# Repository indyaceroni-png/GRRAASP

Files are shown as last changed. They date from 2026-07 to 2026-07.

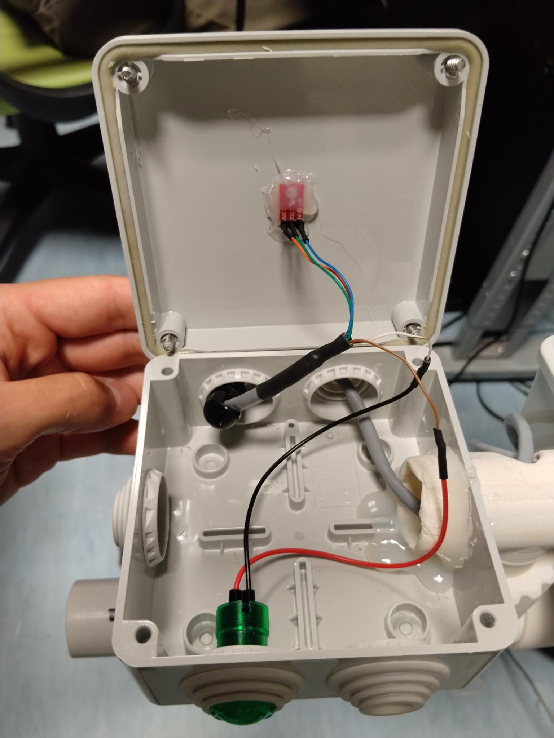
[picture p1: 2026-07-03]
Supplemental Files/Supplemental Files 3/FigureS3.jpeg

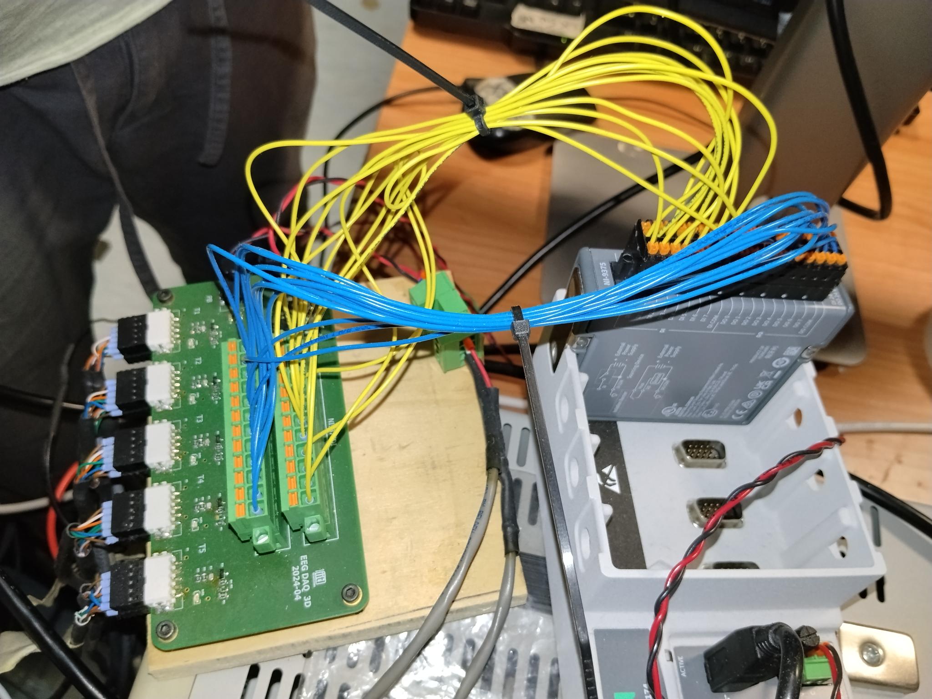
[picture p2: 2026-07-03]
Supplemental Files/Supplemental Files 3/FigureS5.jpeg

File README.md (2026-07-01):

# GRRAASP
This repository contains the LabVIEW software and documentation required to operate the Guided Reaching and Repositioning Adjustable Assessment Platform (GRRAASP), a modular and sensorized setup designed for the standardized neural, muscular, biomechanical, and behavioral assessment of reach-grasp-transport tasks

Folder GRRAASP_LabView contains:
- GRRAASP_main.vi contains the main file controlling the platform.
- Check File Path.vi is needed to set the file path to save logs of the platform.

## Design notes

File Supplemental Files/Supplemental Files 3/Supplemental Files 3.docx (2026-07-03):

Figure S1. Schematic of GRAASP device. Red numbers: (0) 0_baseBracket.stl, (1) 1_middleBracket.stl, (2) 2_topBracket.stl, (3) 3_armLockingSocket.stl, (4) 4_platformLockingSocket.stl, (5) 5_platformTMount.stl, (6) 6_platformSwivelJoint.stl, (7) 7_armTMount.stl, (8) 8_cableClip.stl, (9) 9_lockingRing.stl. Blue numbers: (1)200cm PVC pipes, (2) 55cm PVC pipes, (3) junction box, (4) infrared sensor hole, (5) LED light. Yellow numbers: (1) cylindrical grasp object, (2) spherical grasp object. Black numbers: (1) mobile base, (2) pushbutton

Figure S2. (Left) Detailed view of the installation procedure, showing the insertion of the three 200cm PVC pipes into the 0_baseBracket.stl (Bottom Bracket) and the 1_middleBracket.stl (Middle Alignment Bracket), and the subsequent securing of the entire structure to the central shaft to the mobile base with m4 screws. (Right) Detailed view of the 9_cableClip holding ethernet cables.

Figure S3. Detailed view of the junction box (interaction platform), illustrating the internal wiring and component placement. The electrical connections are mapped as follows: brown wire to LED Positive (Anode), white wire to LED Negative (Cathode), orange wire to Infrared Sensor Positive (VCC), blue wire to Infrared Sensor Ground (GND), and green wire to Infrared Sensor Signal/Data (OUT). To provide strain relief and mechanical stability, the Ethernet cable is looped inside the enclosure. It then exits laterally, passing through the 6_platformSwivelJoint.stl component, which is fitted into a custom-drilled hole on the side of the junction box and permanently secured with glue for added structural integrity.

Figure S4. Detailed view of the custom PCB illustrating the wire placement. The five crimped wires from each cable are inserted into their designated connectors on the board. The connectors are organized into two rows: the top row corresponds to platform indexes 1 through 5 (arranged from left to right), and the bottom row corresponds to platform indexes 6 through 10 (arranged from left to right)

Figure S5. Detailed view of the custom PCB and DAQ module integration. The setup features two pluggable terminal blocks (FKCN 2,5/12-ST-5,08, catalog number 1754665 in Materials.xlsx): one dedicated to the infrared sensors (yellow wires) and another for the LEDs (blue wires). Each pin from these terminal blocks is individually wired to its corresponding input/output pin on the NI-9375 module. The fully wired NI-9375 module is housed within the NI cDAQ-9174 chassis.

Figure S6. Close-up view of the custom PCB, detailing the specific terminal connections: (a) the power supply terminal connector, and (b) the push-button terminal connector.

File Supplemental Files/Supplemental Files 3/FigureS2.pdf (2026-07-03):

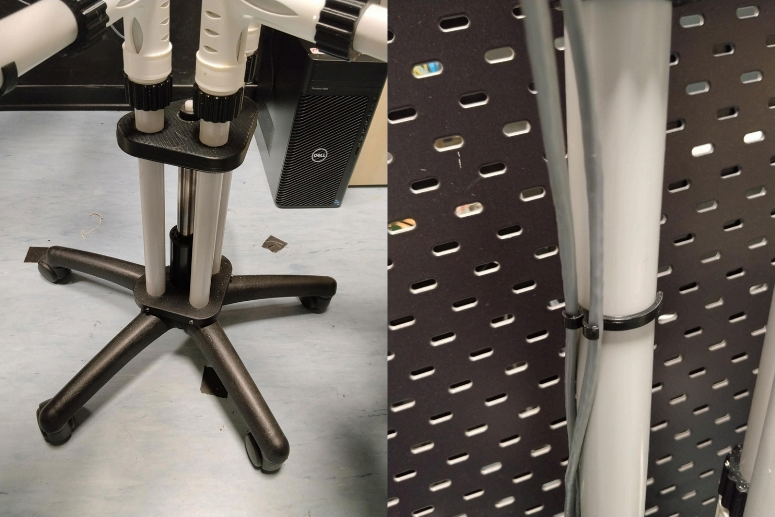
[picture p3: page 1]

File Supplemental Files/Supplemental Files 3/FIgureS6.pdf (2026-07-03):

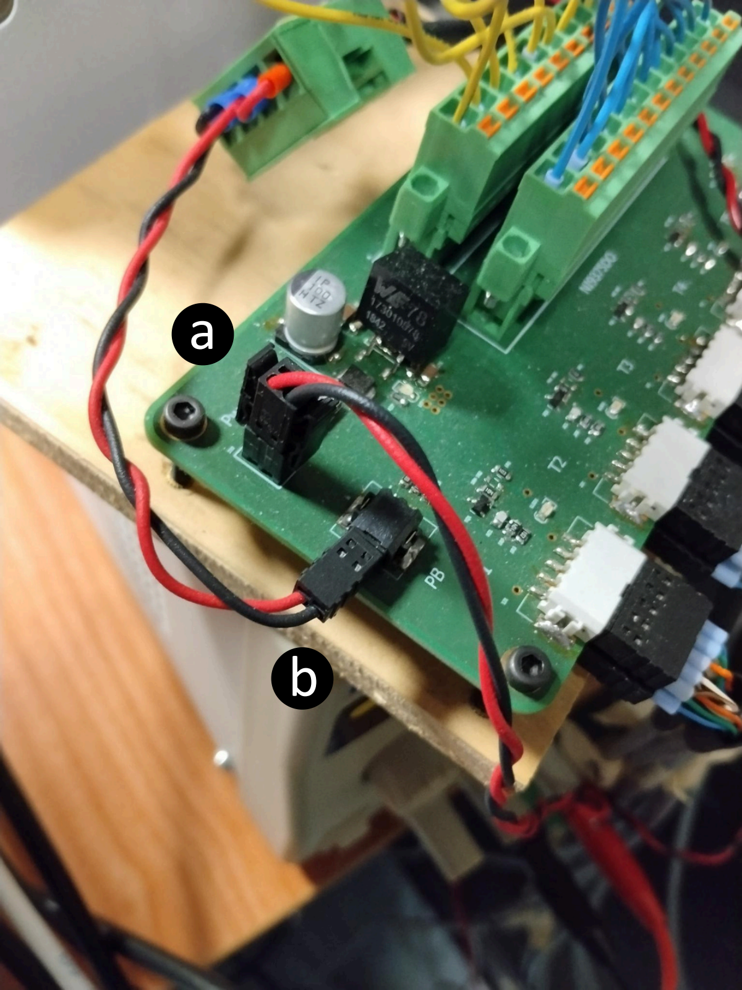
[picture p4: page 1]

a

b

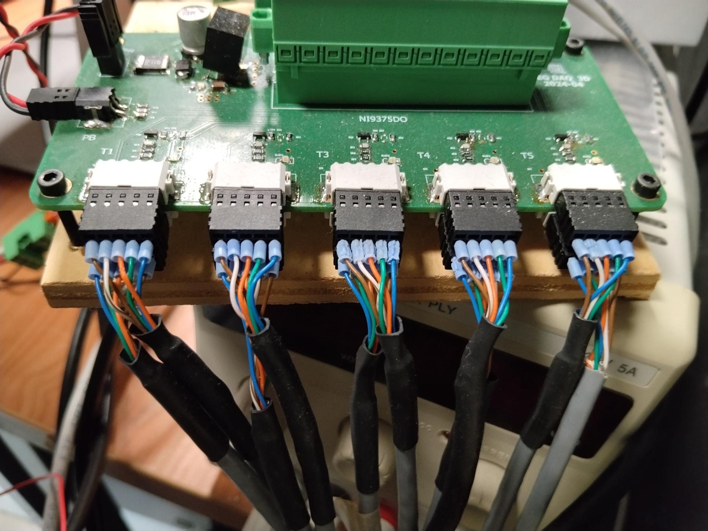
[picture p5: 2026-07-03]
Supplemental Files/Supplemental Files 3/FigureS4.jpeg

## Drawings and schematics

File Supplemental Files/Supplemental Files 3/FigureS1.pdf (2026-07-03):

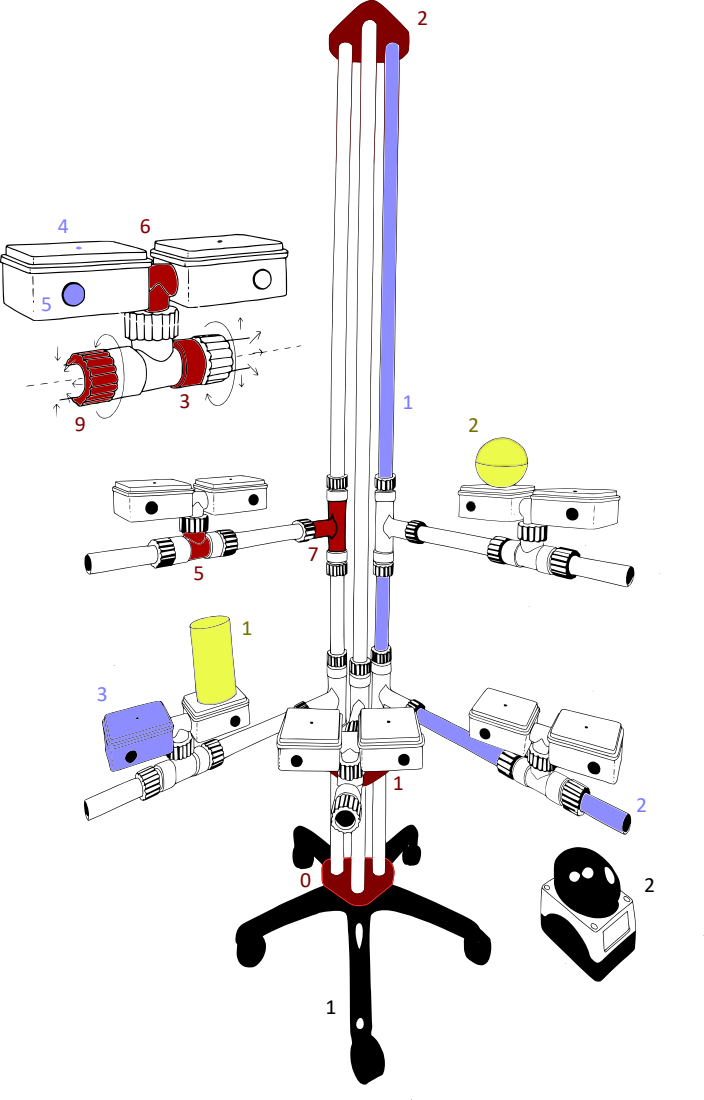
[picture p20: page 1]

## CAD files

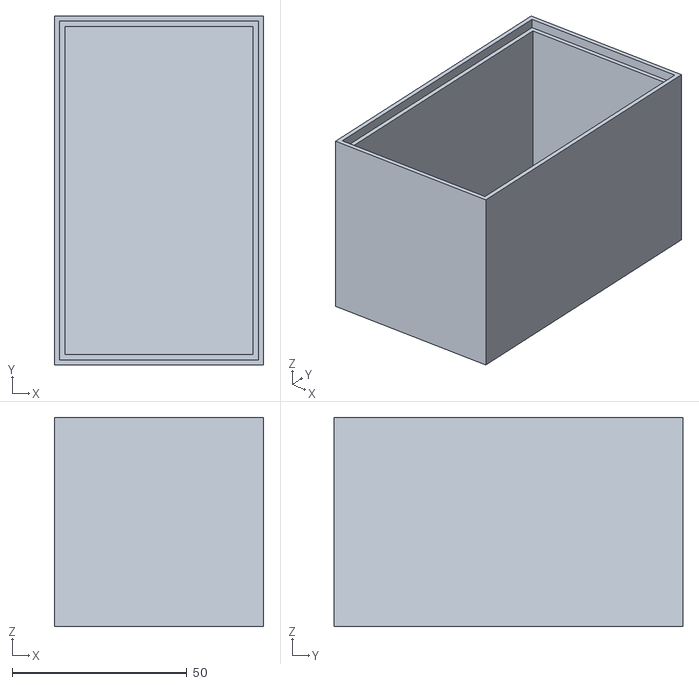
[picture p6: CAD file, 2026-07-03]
Supplemental Files/Supplemental FIles 1/keygrip_0.stl
60.0 x 100.0 x 60.0

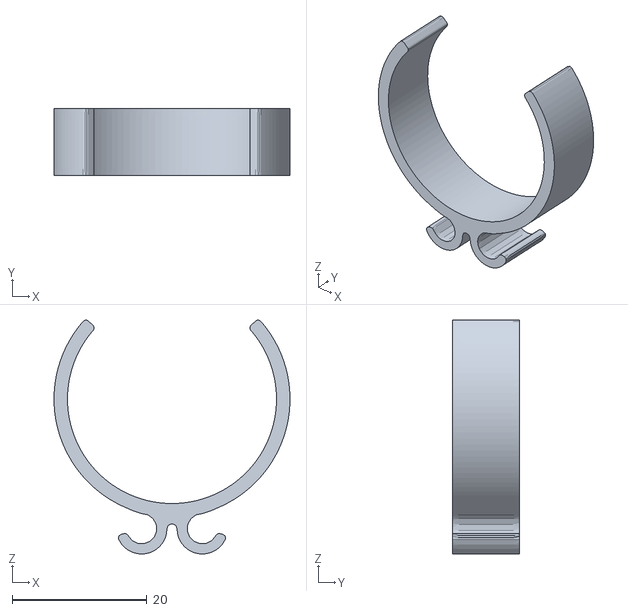
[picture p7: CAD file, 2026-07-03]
Supplemental Files/Supplemental FIles 2/8_cableClip.stl
35.0 x 10.0 x 34.7

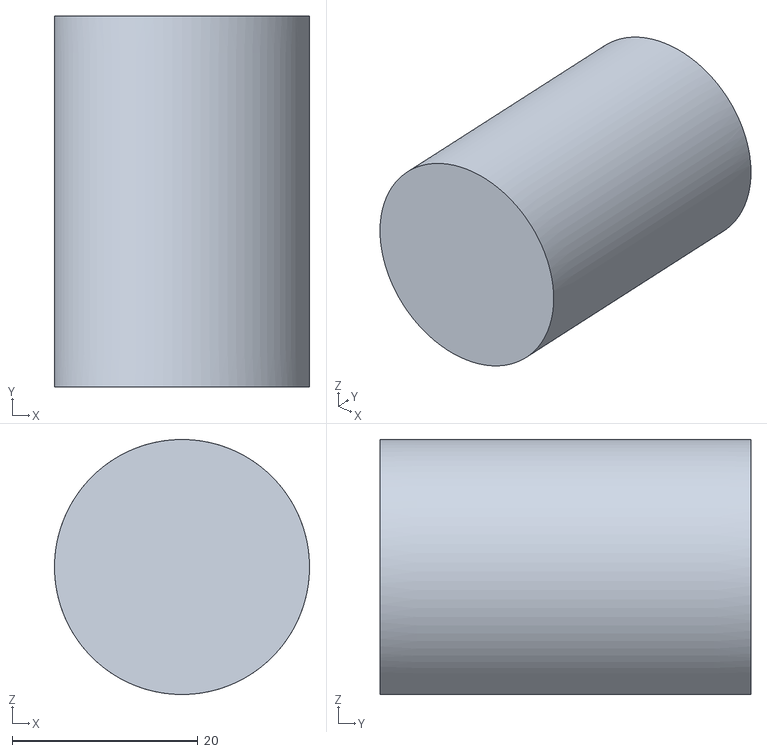
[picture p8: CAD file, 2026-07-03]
Supplemental Files/Supplemental FIles 1/weightSupport.stl
27.5 x 40.0 x 27.5

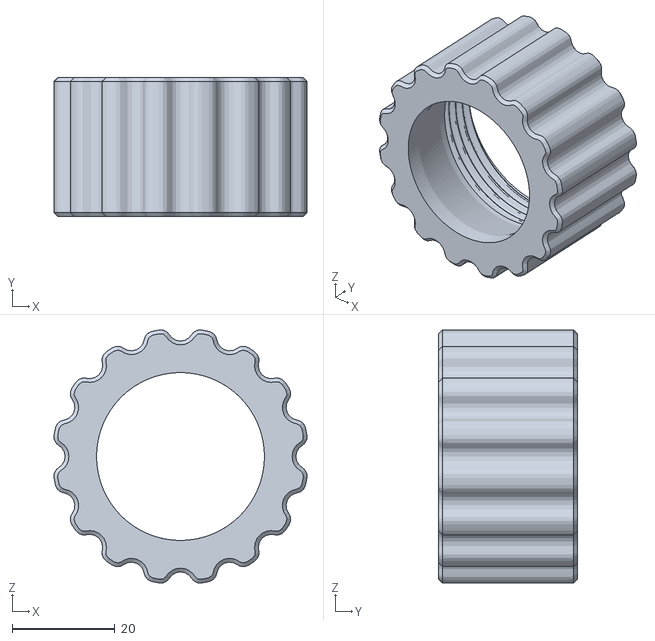
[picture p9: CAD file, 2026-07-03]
Supplemental Files/Supplemental FIles 2/9_lockingRing.stl
49.3 x 27.0 x 49.3

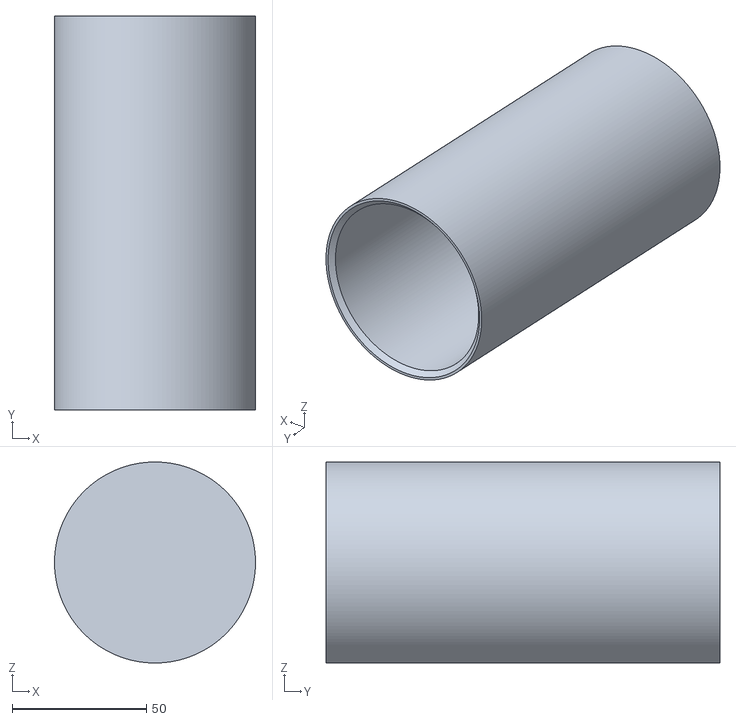
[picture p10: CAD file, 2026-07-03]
Supplemental Files/Supplemental FIles 1/cylinder_0.stl
75.0 x 147.0 x 75.0

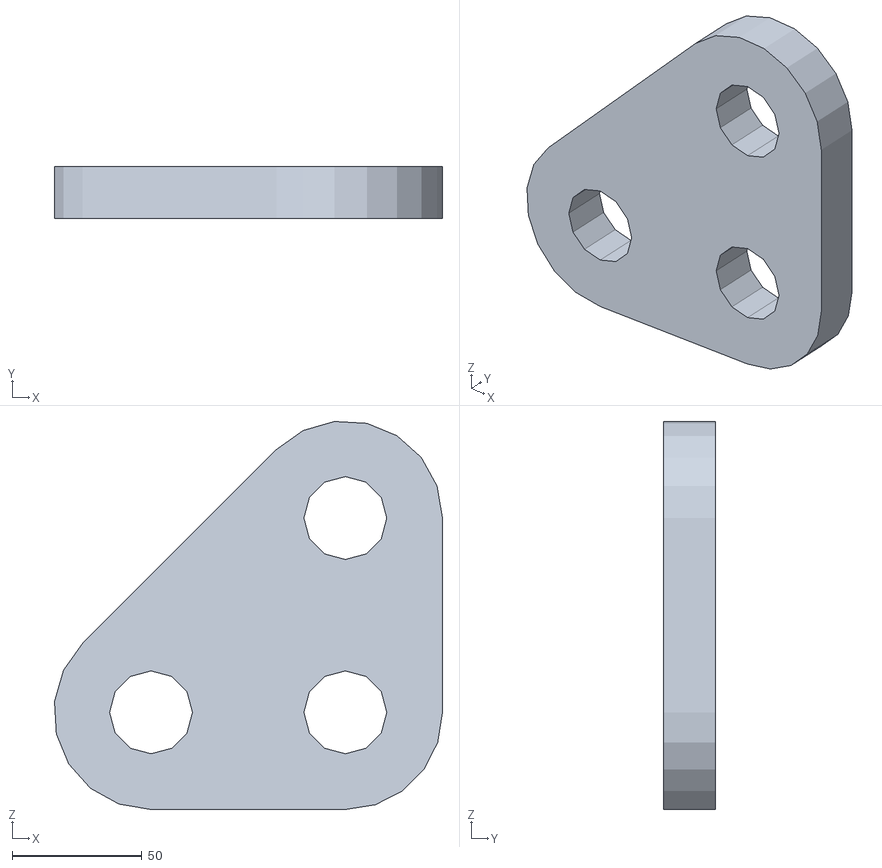
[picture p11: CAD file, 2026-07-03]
Supplemental Files/Supplemental FIles 2/2_topBracket.stl
149.8 x 20.0 x 149.8

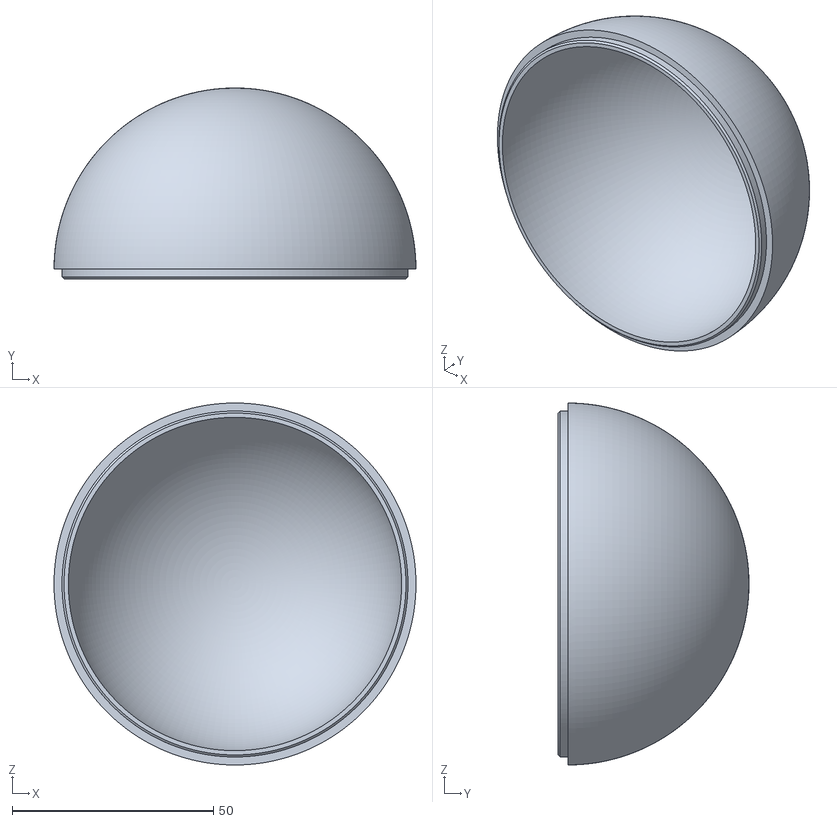
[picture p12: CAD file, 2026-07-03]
Supplemental Files/Supplemental FIles 1/sphere_1.stl
90.0 x 47.5 x 90.0

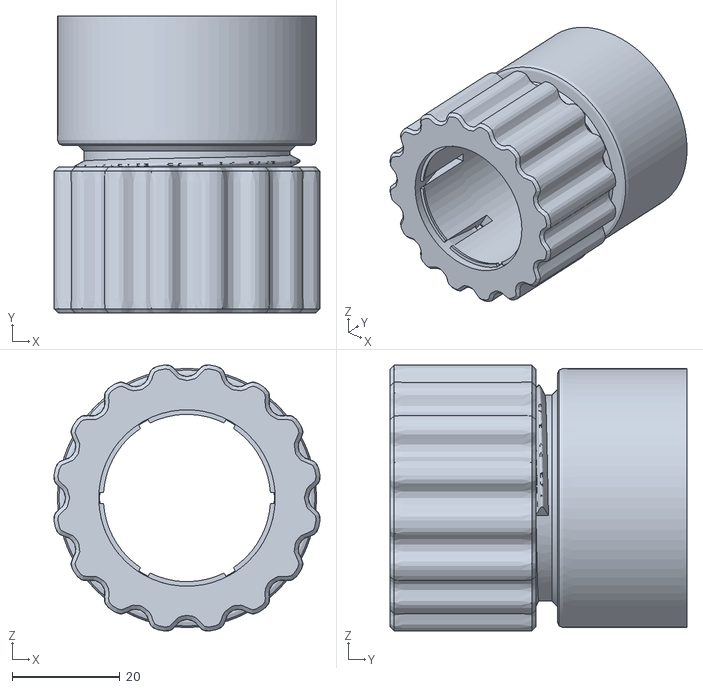
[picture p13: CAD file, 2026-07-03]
Supplemental Files/Supplemental FIles 2/4_platformLockingSocket.stl
49.3 x 55.0 x 49.3

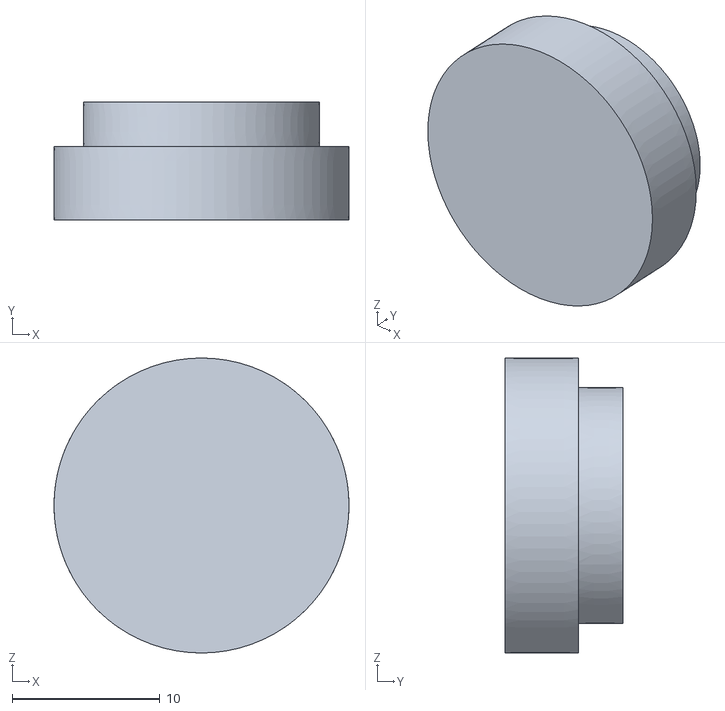
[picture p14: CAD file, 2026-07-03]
Supplemental Files/Supplemental FIles 1/tridigital_0.stl
20.0 x 8.00 x 20.0

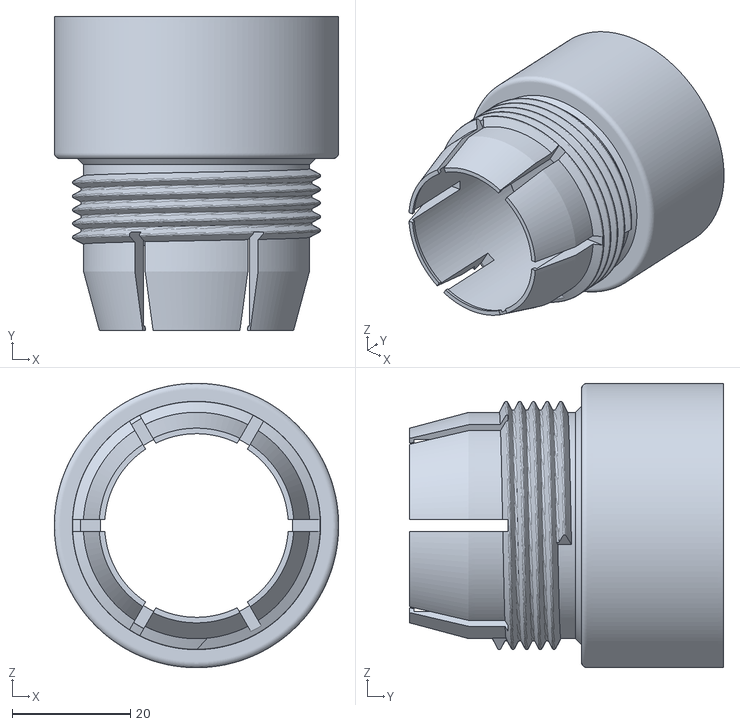
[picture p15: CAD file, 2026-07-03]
Supplemental Files/Supplemental FIles 2/3_armLockingSocket.stl
48.0 x 53.0 x 48.0

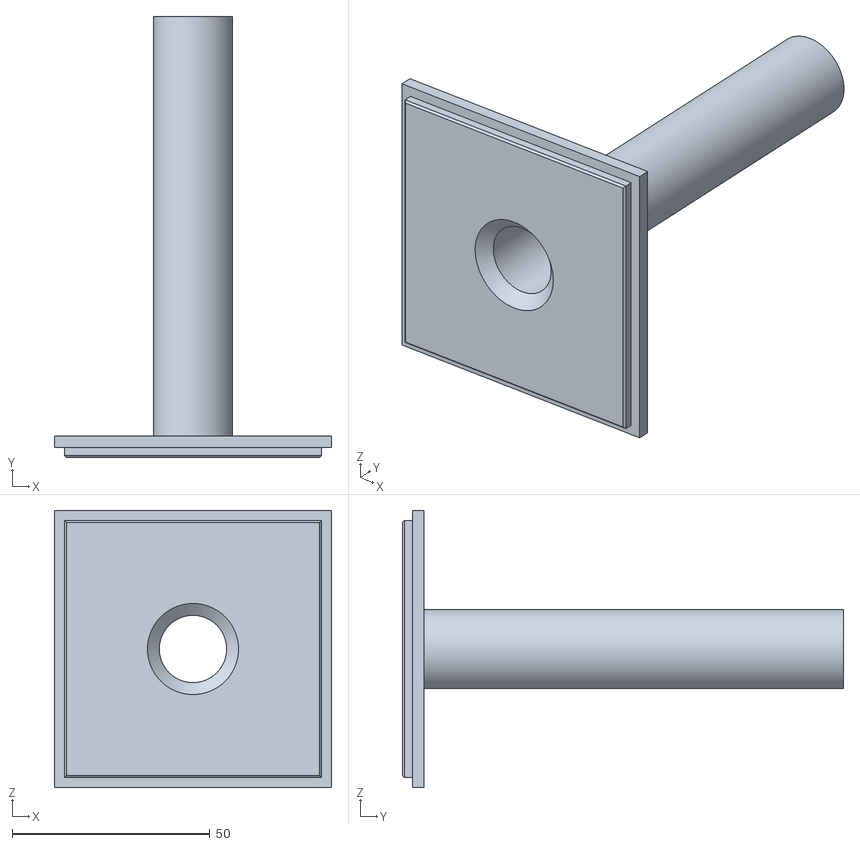
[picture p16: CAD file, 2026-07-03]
Supplemental Files/Supplemental FIles 1/tridigital_1.stl
70.0 x 111.5 x 70.0

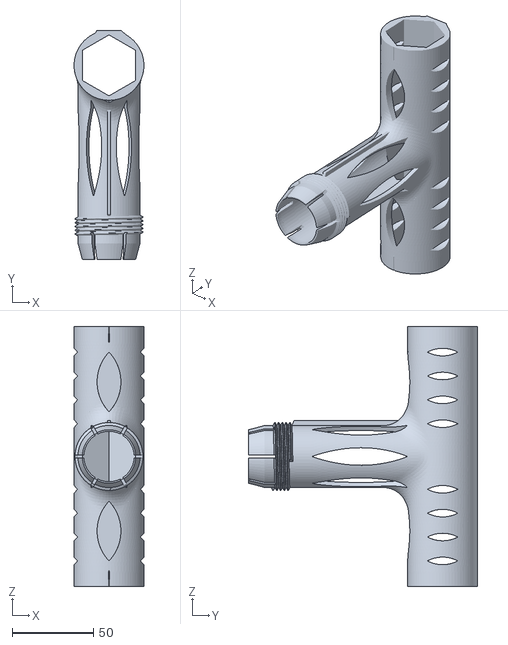
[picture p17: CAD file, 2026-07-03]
Supplemental Files/Supplemental FIles 2/7_armTMount.stl
43.0 x 141.0 x 160.0

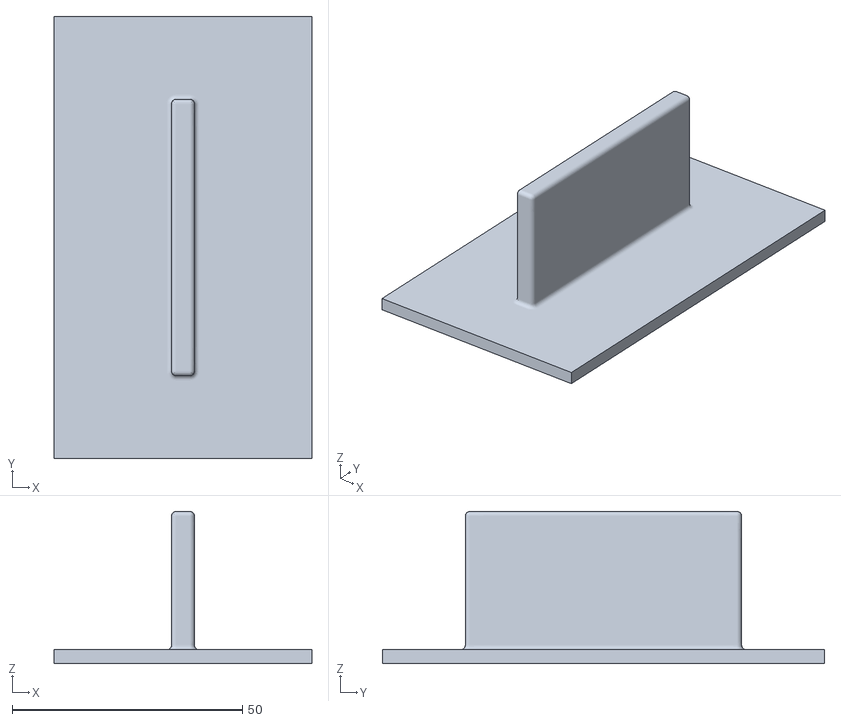
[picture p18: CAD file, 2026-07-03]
Supplemental Files/Supplemental FIles 1/keygrip_1.stl
56.0 x 96.0 x 33.0

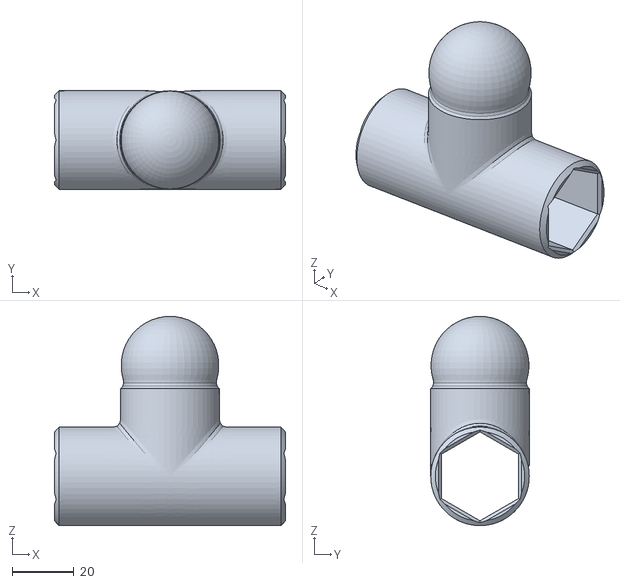
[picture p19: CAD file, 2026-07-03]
Supplemental Files/Supplemental FIles 2/6_platformSwivelJoint.stl
75.0 x 32.0 x 67.9

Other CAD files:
Supplemental Files/Supplemental FIles 1/sphere_2.stl
Supplemental Files/Supplemental FIles 2/0_baseBracket.stl
Supplemental Files/Supplemental FIles 1/cylinder_1.stl
Supplemental Files/Supplemental FIles 2/5_platformTMount.stl
Supplemental Files/Supplemental FIles 1/tridigital_2.stl
Supplemental Files/Supplemental FIles 2/1_middleBrecket.stl
